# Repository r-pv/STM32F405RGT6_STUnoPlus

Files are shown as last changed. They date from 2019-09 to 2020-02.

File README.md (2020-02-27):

# STM32F405RGT6 STUno+

An ST development board based on the STM32F405RGT6/STM32F405RG (Clock: 168MHz, Flash: 1024Kb, Ram:194Kb) MCU (LQFP-64) compatible with STM32Duino (Arduino).

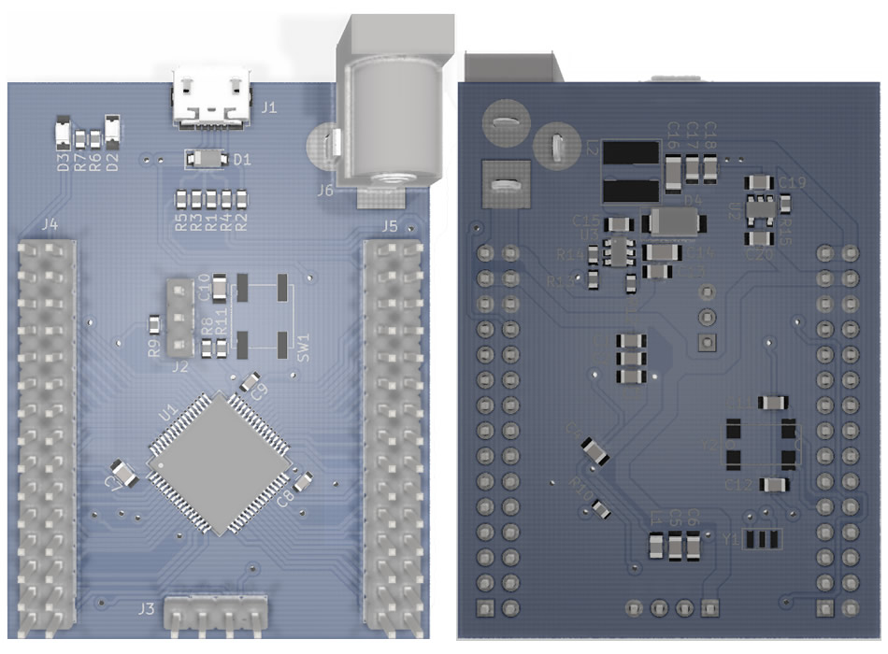
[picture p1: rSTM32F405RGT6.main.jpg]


## Pinout:

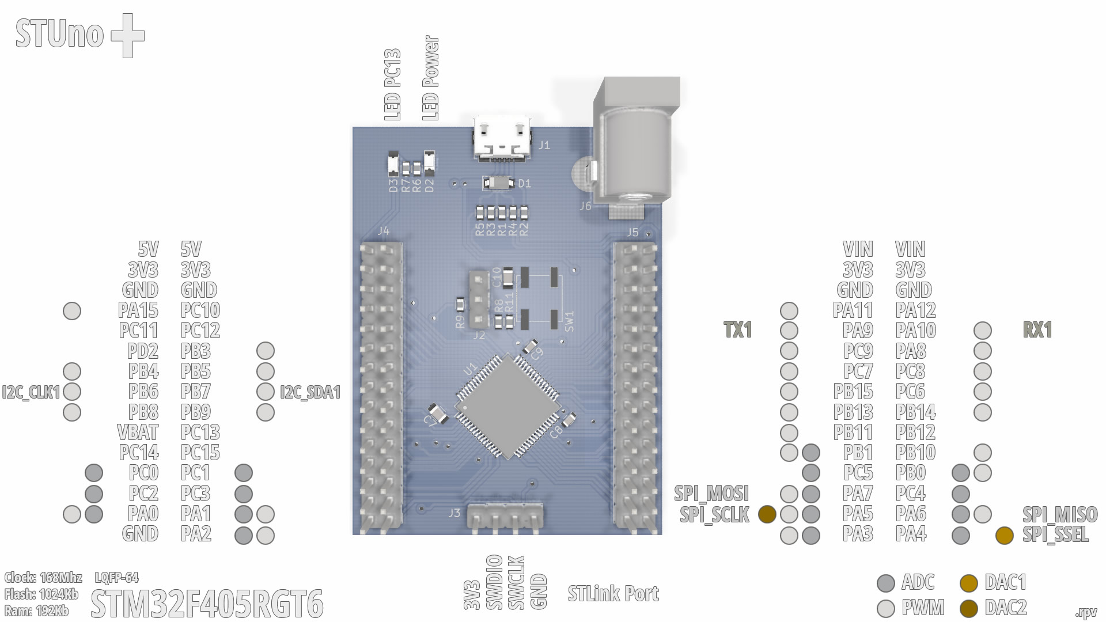
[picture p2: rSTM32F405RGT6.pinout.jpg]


## Files and Folders description

- **RBOARD_F405RGT6** it's the variant board for the STM32 Arduino Core.
- **rSTM32F405RGT6_B** it's the KiCAD 5.1.2 project.
- **rSTM32F405RGT6.schematic.pdf** the schematic.

## Install

- This requires the [STM32 core for arduino](https://github.com/stm32duino/Arduino_Core_STM32/), the ST original.
- I used this [guide to add the board](https://github.com/stm32duino/wiki/wiki/Add-a-new-variant-(board)), you can check it or continue with my suggestions to install the new board.
- Copy the **"RBOARD_F405RGT6"** folder to the Arduino **"variants"** folder, in win7 is located at: **c:\Users\\<USERNAME\>\AppData\Local\Arduino15\packages\STM32\hardware\stm32\1.8.0\variants**
- Edit the **"boards.txt"** file, in win7 is located at a lever up than the "variants" folder, search for the **Generic F4** board line and add the lines to leave it as I show you next:

```
# Adafruit Feather STM32F405 board
GenF4.menu.pnum.FEATHER_F405=Adafruit Feather STM32F405
GenF4.menu.pnum.FEATHER_F405.upload.maximum_size=1048576
GenF4.menu.pnum.FEATHER_F405.upload.maximum_data_size=131072
GenF4.menu.pnum.FEATHER_F405.build.board=FEATHER_F405
GenF4.menu.pnum.FEATHER_F405.build.product_line=STM32F405xx
GenF4.menu.pnum.FEATHER_F405.build.variant=FEATHER_F405

# STM32F405RGT6 STUnoPlus board
GenF4.menu.pnum.RBOARD_F405RGT6=STM32F405RGT6 STUnoPlus
GenF4.menu.pnum.RBOARD_F405RGT6.upload.maximum_size=1048576
GenF4.menu.pnum.RBOARD_F405RGT6.upload.maximum_data_size=131072
GenF4.menu.pnum.RBOARD_F405RGT6.build.board=RBOARD_F405RGT6
GenF4.menu.pnum.RBOARD_F405RGT6.build.product_line=STM32F405xx
GenF4.menu.pnum.RBOARD_F405RGT6.build.variant=RBOARD_F405RGT6
```
(add after the _"# Adafruit Feather STM32F405 board"_ section).

That's all.

So on the arduino IDE, on the **boards** menu pick the option _"Generic STM32F4 series"_ and the **board part number:** suboption pick the _"STM32F405RGT6 STUnoPlus"_ option.

**Note:** while adafruit board and mine use the same MCU there are not compatible variants: adafruit uses a 12mhz external crystal, mine uses an 8mhz.

## The real board

**Front**

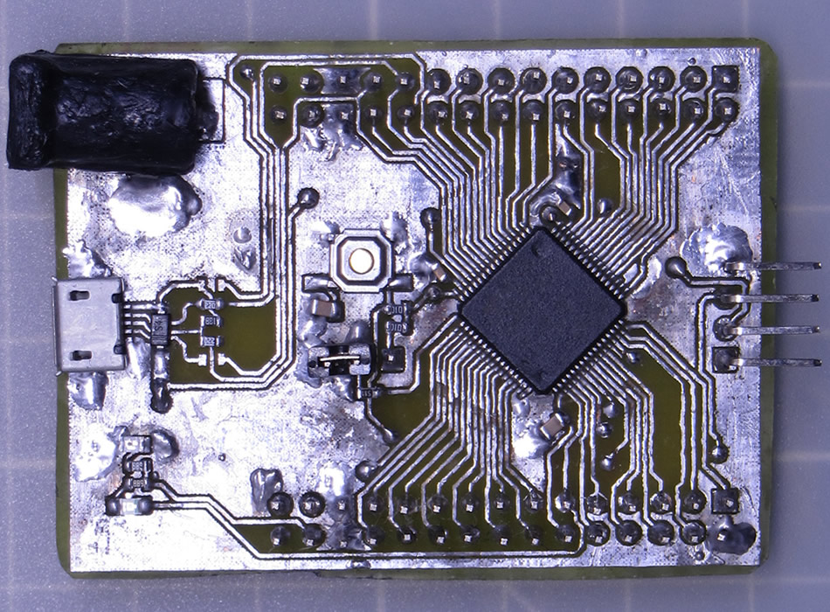
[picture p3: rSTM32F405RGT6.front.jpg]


_*I submerge the boards on a painters solvent bath to clean the flux residue which I haven't any problem until the DC jack came, as you see, didn't took the solvent bath kindly :P_

**Back**

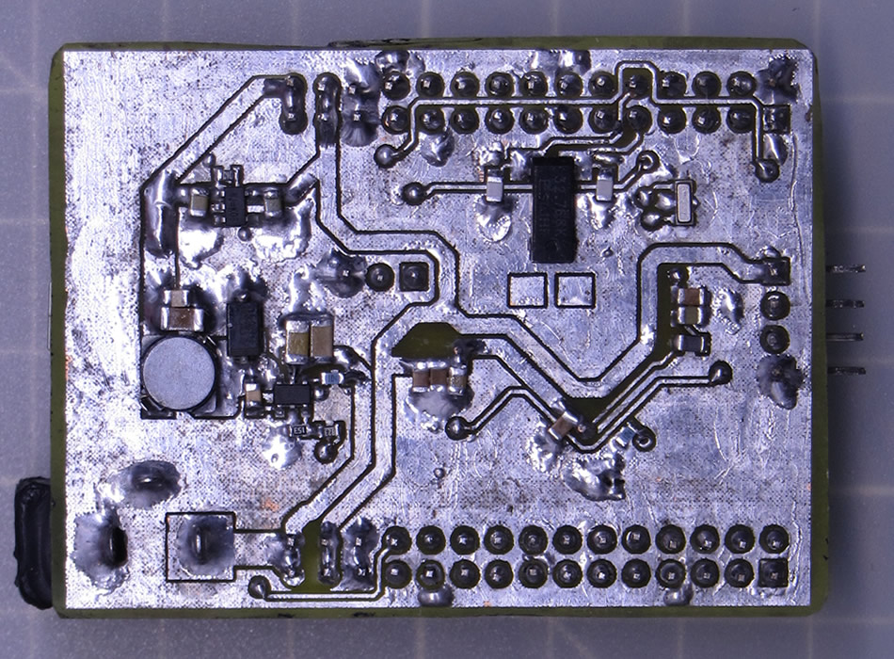
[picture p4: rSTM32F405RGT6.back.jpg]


_*The footprint for the second crystal (Y2) was wrong on this board but it's already corrected on the KiCAD files._

## Running some tests

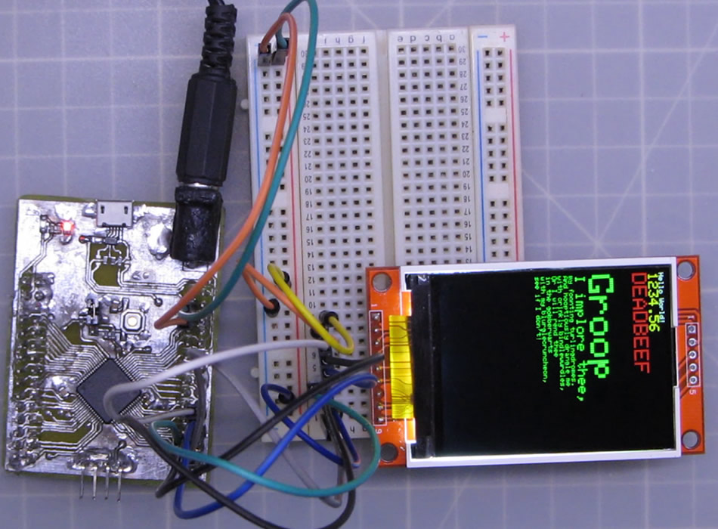
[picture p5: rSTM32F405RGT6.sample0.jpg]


The **STUno+** running the Adafruit ILI9341 library over hardware SPI.

_Video in progress..._

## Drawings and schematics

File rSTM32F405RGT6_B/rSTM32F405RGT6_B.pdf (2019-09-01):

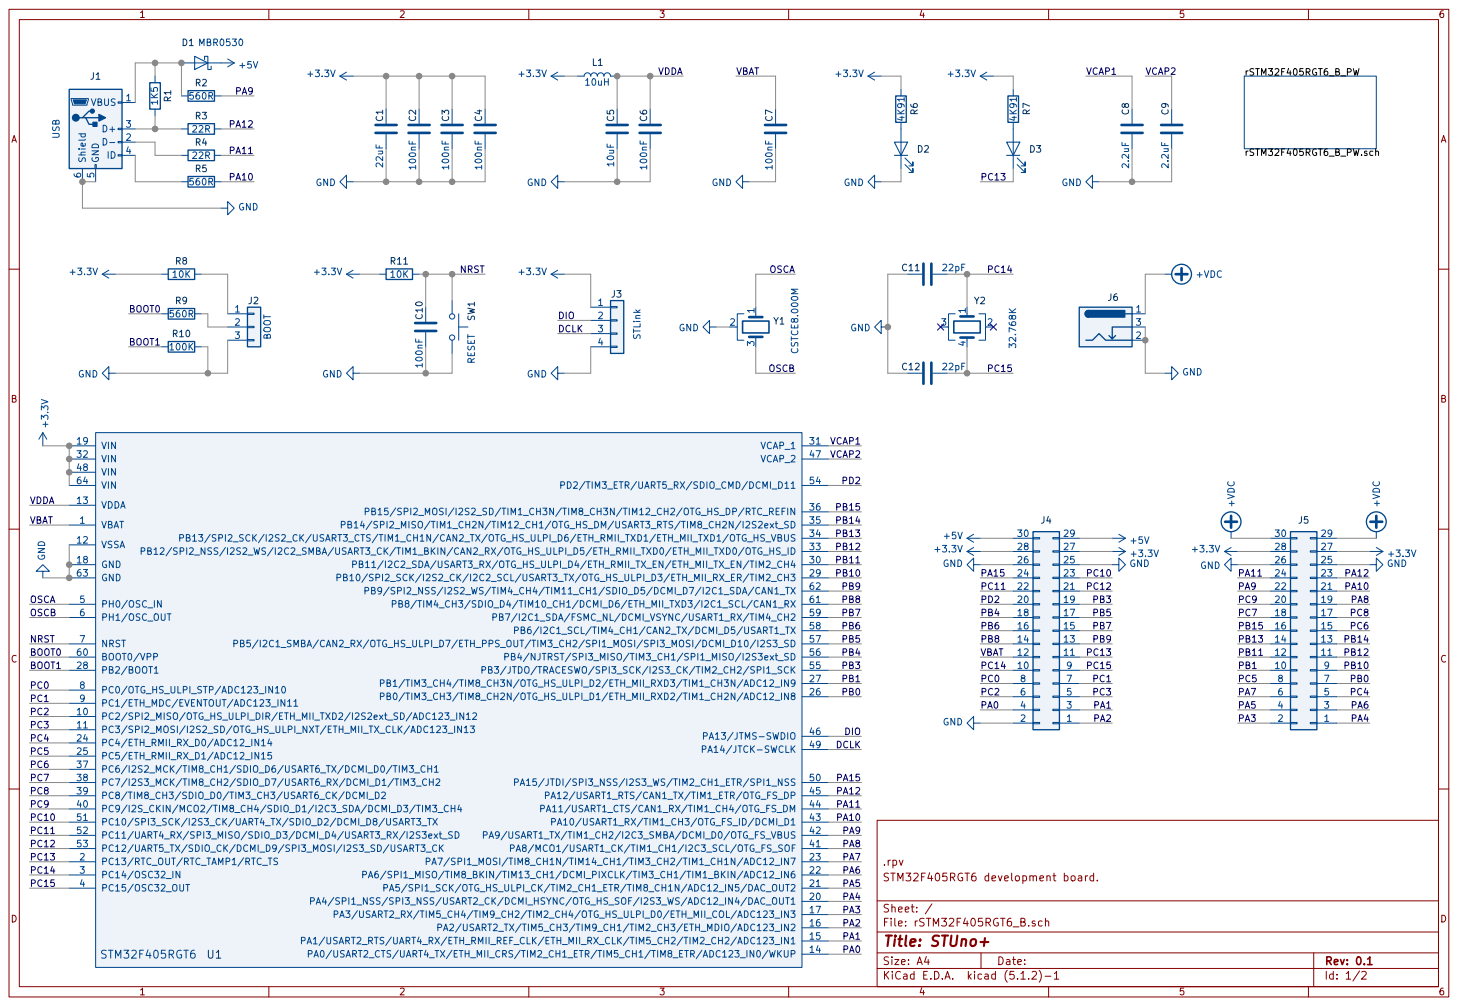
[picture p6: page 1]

File: rSTM32F405RGT6_B.sch Sheet: / STM32F405RGT6 development board.

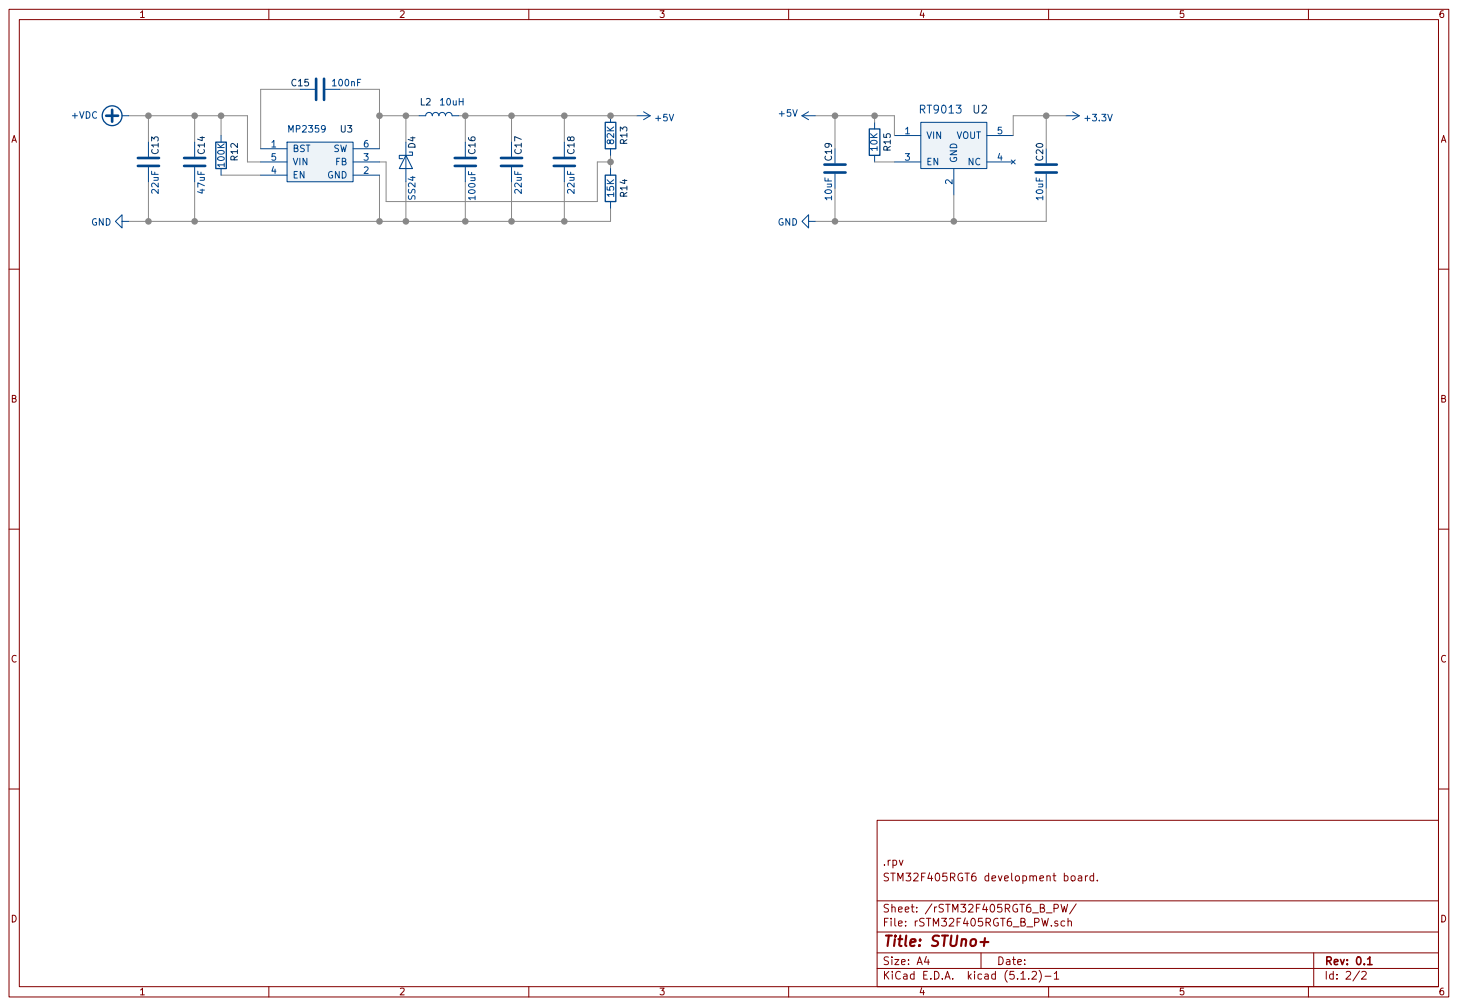
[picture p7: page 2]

2 EN 3 NC 4 VOUT 5 RT9013 U2 10K R15 +5V R12 100K GND

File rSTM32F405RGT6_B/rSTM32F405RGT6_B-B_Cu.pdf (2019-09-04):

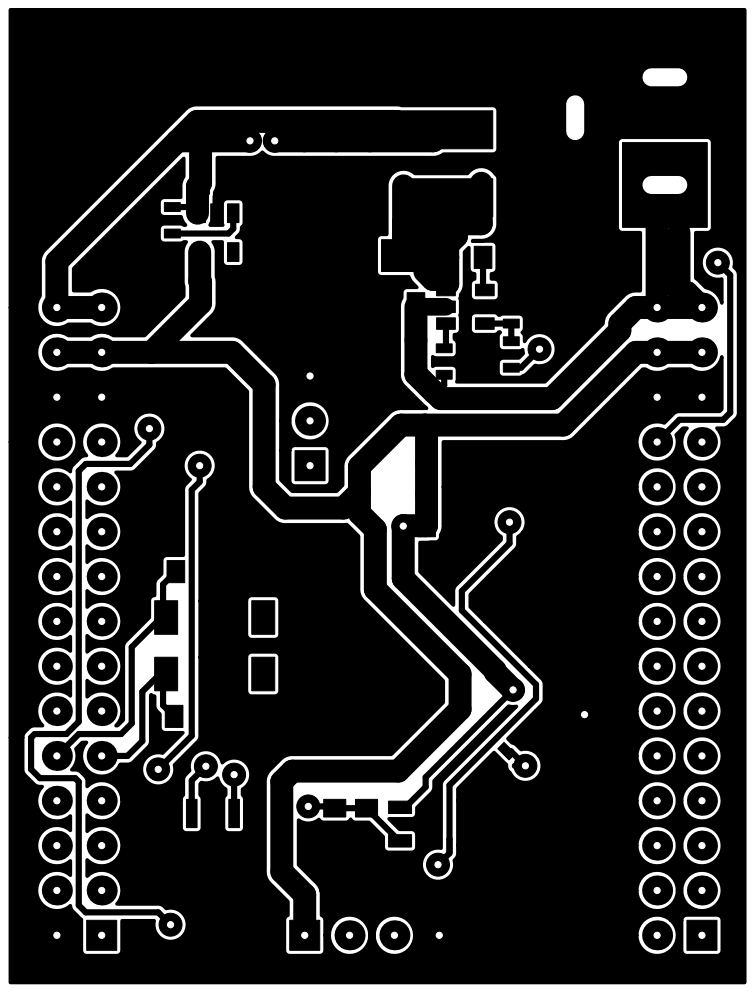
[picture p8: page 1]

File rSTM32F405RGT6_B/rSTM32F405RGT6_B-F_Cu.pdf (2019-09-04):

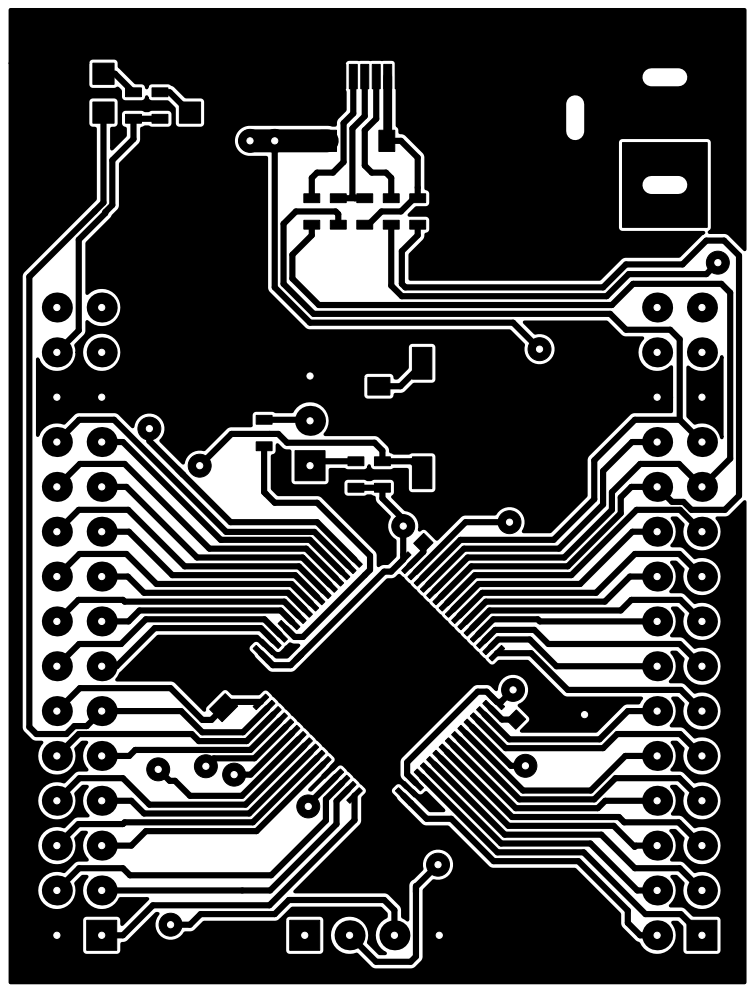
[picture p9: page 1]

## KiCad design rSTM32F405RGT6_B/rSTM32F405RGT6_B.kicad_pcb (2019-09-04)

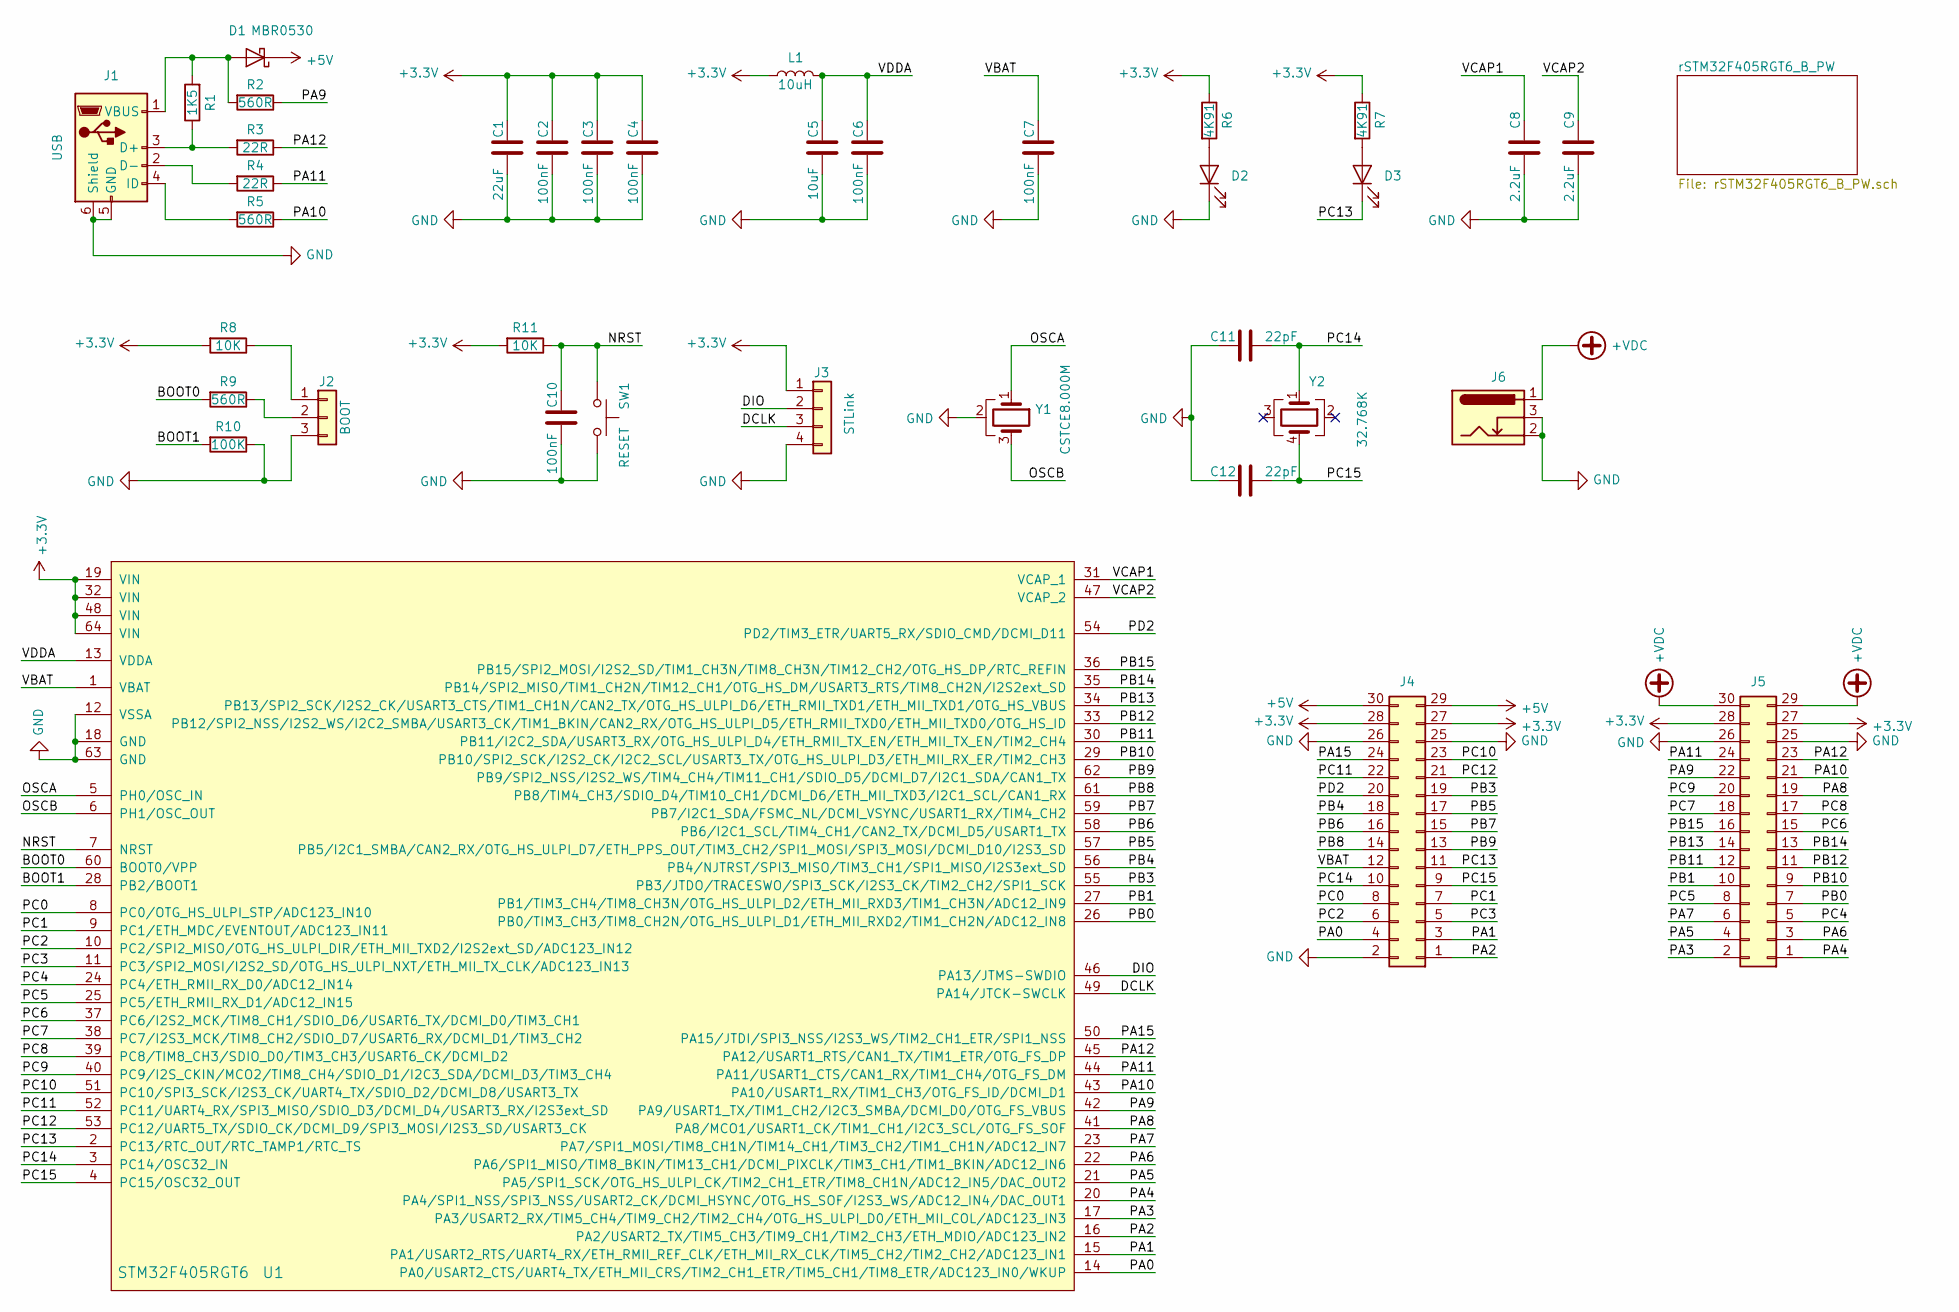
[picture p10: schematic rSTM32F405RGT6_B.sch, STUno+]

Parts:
C1: 22uF; C_0805
C2, C3, C4, C6, C7, C10: 100nF; C_0805
C5: 10uF; C_0805
C8, C9: 2.2uF; C_0603
C11, C12: 22pF; C_0805
D1: MBR0530; D_SOD-123
D2, D3: LED; LED_0805
J1: USB; USB_Micro-B_Molex_47346-0001
J2: BOOT; Pin_Header_Straight_1x03_Pitch2.54mm
J3: STLink; Pin_Header_Straight_1x04_Pitch2.54mm
J4, J5: Pin_Header_Straight_2x15_Pitch2.54mm
J6: JACK_ALIM
L1: 10uH; L_0805
R1: 1K5; R_0603
R2, R5, R9: 560R; R_0603
R3, R4: 22R; R_0603
R6, R7: 4K91; R_0603
R8, R11: 10K; R_0603
R10: 100K; R_0603
SW1: RESET; Switch_SMD_5.2x6.4_reset
U1: STM32F405RGT6; LQFP-64_10x10mm_Pitch0.5mm
Y1: CSTCE8.000M; Crystal_CSTCE_3pin_3.2x1.3
Y2: 32.768K; Crystal_4pin_SMD_2.5x4.6

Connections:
+3V3: C1.1, C2.1, C3.1, C4.1, J3.1, J4.27, J4.28, J5.27, J5.28, L1.1, R6.1, R7.1, R8.2, R11.2, U1.19 (VIN), U1.32 (VIN), U1.48 (VIN), U1.64 (VIN); also elsewhere on the board
+5V: D1.1 (K), J4.29, J4.30; also elsewhere on the board
+VDC: J5.29, J5.30, J6.1; also elsewhere on the board
/BOOT0: R9.2, U1.60 (BOOT0/VPP)
/BOOT1: R10.2, U1.28 (PB2/BOOT1)
/DCLK: J3.3, U1.49 (PA14/JTCK-SWCLK)
/DIO: J3.2, U1.46 (PA13/JTMS-SWDIO)
/NRST: C10.1, R11.1, SW1.1, U1.7 (NRST)
/OSCA: U1.5 (PH0/OSC_IN), Y1.1
/OSCB: U1.6 (PH1/OSC_OUT), Y1.3
/PA0: J4.4, U1.14 (PA0/USART2_CTS/UART4_TX/ETH_MII_CRS/TIM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)
/PA1: J4.3, U1.15 (PA1/USART2_RTS/UART4_RX/ETH_RMII_REF_CL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)
/PA2: J4.1, U1.16 (PA2/USART2_TX/TIM5_CH3/TIM9_CH1/TIM2_CH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)
/PA3: J5.2, U1.17 (PA3/USART2_RX/TIM5_CH4/TIM9_CH2/TIM2_CH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)
/PA4: J5.1, U1.20 (PA4/SPI1_NSS/SPI3_NSS/USART2_CK/DCMI_HS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)
/PA5: J5.4, U1.21 (PA5/SPI1_SCK/OTG_HS_ULPI_CK/TIM2_CH1_ET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)
/PA6: J5.3, U1.22 (PA6/SPI1_MISO/TIM8_BKIN/TIM13_CH1/DCMI_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)
/PA7: J5.6, U1.23 (PA7/SPI1_MOSI/TIM8_CH1N/TIM14_CH1/TIM3_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)
/PA8: J5.19, U1.41 (PA8/MCO1/USART1_CK/TIM1_CH1/I2C3_SCL/OT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)
/PA9: J5.22, R2.1, U1.42 (PA9/USART1_TX/TIM1_CH2/I2C3_SMBA/DCMI_D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)
/PA10: J5.21, R5.1, U1.43 (PA10/USART1_RX/TIM1_CH3/OTG_FS_ID/DCMI_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)
/PA11: J5.24, R4.1, U1.44 (PA11/USART1_CTS/CAN1_RX/TIM1_CH4/OTG_FS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)
/PA12: J5.23, R3.1, U1.45 (PA12/USART1_RTS/CAN1_TX/TIM1_ETR/OTG_FS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)
/PA15: J4.24, U1.50 (PA15/JTDI/SPI3_NSS/I2S3_WS/TIM2_CH1_ETR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)
/PB0: J5.7, U1.26 (PB0/TIM3_CH3/TIM8_CH2N/OTG_HS_ULPI_D1/E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)
/PB1: J5.10, U1.27 (PB1/TIM3_CH4/TIM8_CH3N/OTG_HS_ULPI_D2/E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)
/PB3: J4.19, U1.55 (PB3/JTDO/TRACESWO/SPI3_SCK/I2S3_CK/TIM2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)
/PB4: J4.18, U1.56 (PB4/NJTRST/SPI3_MISO/TIM3_CH1/SPI1_MISO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)
/PB5: J4.17, U1.57 (PB5/I2C1_SMBA/CAN2_RX/OTG_HS_ULPI_D7/ET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)
/PB6: J4.16, U1.58 (PB6/I2C1_SCL/TIM4_CH1/CAN2_TX/DCMI_D5/U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)
/PB7: J4.15, U1.59 (PB7/I2C1_SDA/FSMC_NL/DCMI_VSYNC/USART1_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)
/PB8: J4.14, U1.61 (PB8/TIM4_CH3/SDIO_D4/TIM10_CH1/DCMI_D6/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)
/PB9: J4.13, U1.62 (PB9/SPI2_NSS/I2S2_WS/TIM4_CH4/TIM11_CH1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)
/PB10: J5.9, U1.29 (PB10/SPI2_SCK/I2S2_CK/I2C2_SCL/USART3_T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)
/PB11: J5.12, U1.30 (PB11/I2C2_SDA/USART3_RX/OTG_HS_ULPI_D4/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)
/PB12: J5.11, U1.33 (PB12/SPI2_NSS/I2S2_WS/I2C2_SMBA/USART3_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)
/PB13: J5.14, U1.34 (PB13/SPI2_SCK/I2S2_CK/USART3_CTS/TIM1_C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)
/PB14: J5.13, U1.35 (PB14/SPI2_MISO/TIM1_CH2N/TIM12_CH1/OTG_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)
/PB15: J5.16, U1.36 (PB15/SPI2_MOSI/I2S2_SD/TIM1_CH3N/TIM8_C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)
/PC0: J4.8, U1.8 (PC0/OTG_HS_ULPI_STP/ADC123_IN10)
/PC1: J4.7, U1.9 (PC1/ETH_MDC/EVENTOUT/ADC123_IN11)
/PC2: J4.6, U1.10 (PC2/SPI2_MISO/OTG_HS_ULPI_DIR/ETH_MII_T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)
/PC3: J4.5, U1.11 (PC3/SPI2_MOSI/I2S2_SD/OTG_HS_ULPI_NXT/E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)
/PC4: J5.5, U1.24 (PC4/ETH_RMII_RX_D0/ADC12_IN14)
/PC5: J5.8, U1.25 (PC5/ETH_RMII_RX_D1/ADC12_IN15)
/PC6: J5.15, U1.37 (PC6/I2S2_MCK/TIM8_CH1/SDIO_D6/USART6_TX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)
/PC7: J5.18, U1.38 (PC7/I2S3_MCK/TIM8_CH2/SDIO_D7/USART6_RX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)
/PC8: J5.17, U1.39 (PC8/TIM8_CH3/SDIO_D0/TIM3_CH3/USART6_CK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)
/PC9: J5.20, U1.40 (PC9/I2S_CKIN/MCO2/TIM8_CH4/SDIO_D1/I2C3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)
/PC10: J4.23, U1.51 (PC10/SPI3_SCK/I2S3_CK/UART4_TX/SDIO_D2/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)
/PC11: J4.22, U1.52 (PC11/UART4_RX/SPI3_MISO/SDIO_D3/DCMI_D4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)
/PC12: J4.21, U1.53 (PC12/UART5_TX/SDIO_CK/DCMI_D9/SPI3_MOSI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)
/PC13: D3.1 (K), J4.11, U1.2 (PC13/RTC_OUT/RTC_TAMP1/RTC_TS)
/PC14: C11.1, J4.10, U1.3 (PC14/OSC32_IN), Y2.1
/PC15: C12.1, J4.9, U1.4 (PC15/OSC32_OUT), Y2.4
/PD2: J4.20, U1.54 (PD2/TIM3_ETR/UART5_RX/SDIO_CMD/DCMI_D11)
/VBAT: C7.1, J4.12, U1.1 (VBAT)
/VCAP1: C8.1, U1.31 (VCAP_1)
/VCAP2: C9.1, U1.47 (VCAP_2)
/VDDA: C5.1, C6.1, L1.2, U1.13 (VDDA)
GND: C1.2, C2.2, C3.2, C4.2, C5.2, C6.2, C7.2, C8.2, C9.2, C10.2, C11.2, C12.2, D2.1 (K), J1.5 (GND), J1.6 (Shield), J2.3, J3.4, J4.2, J4.25, J4.26, J5.25, J5.26, J6.2, J6.3, R10.1, SW1.2, U1.12 (VSSA), U1.18 (GND), U1.63 (GND), Y1.2; also elsewhere on the board
unnamed: D1.2 (A), J1.1 (VBUS), R1.2, R2.2
unnamed: D2.2 (A), R6.2
unnamed: D3.2 (A), R7.2
unnamed: J1.2 (D-), R4.2
unnamed: J1.3 (D+), R1.1, R3.2
unnamed: J1.4 (ID), R5.2
unnamed: J2.1, R8.1
unnamed: J2.2, R9.1

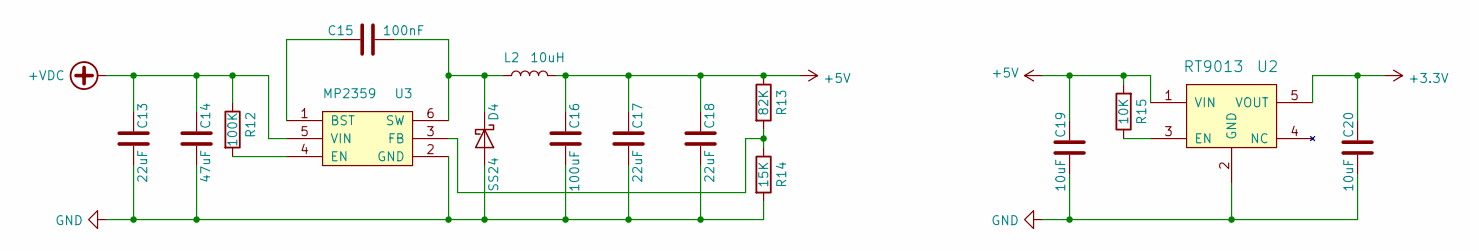
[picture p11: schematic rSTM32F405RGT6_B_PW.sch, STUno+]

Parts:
C13, C17, C18: 22uF; C_0805
C14: 47uF; C_1206
C15: 100nF; C_0805
C16: 100uF; C_1206
C19, C20: 10uF; C_0805
D4: SS24; D_SMA
L2: 10uH; Inductor-CD54
R12: 100K; R_0603
R13: 82K; R_0603
R14: 15K; R_0603
R15: 10K; R_0603
U2: RT9013; SOT-23-5
U3: MP2359; SOT-23-6

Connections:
+3V3: C20.1, U2.5 (VOUT); also elsewhere on the board
+5V: C16.1, C17.1, C18.1, C19.1, L2.2, R13.1, R15.2, U2.1 (VIN); also elsewhere on the board
+VDC: C13.1, C14.1, R12.1, U3.5 (VIN); also elsewhere on the board
GND: C13.2, C14.2, C16.2, C17.2, C18.2, C19.2, C20.2, D4.2 (A), R14.2, U2.2 (GND), U3.2 (GND); also elsewhere on the board
unnamed: C15.1, D4.1 (K), L2.1, U3.6 (SW)
unnamed: C15.2, U3.1 (BST)
unnamed: R12.2, U3.4 (EN)
unnamed: R13.2, R14.1, U3.3 (FB)
unnamed: R15.1, U2.3 (EN)

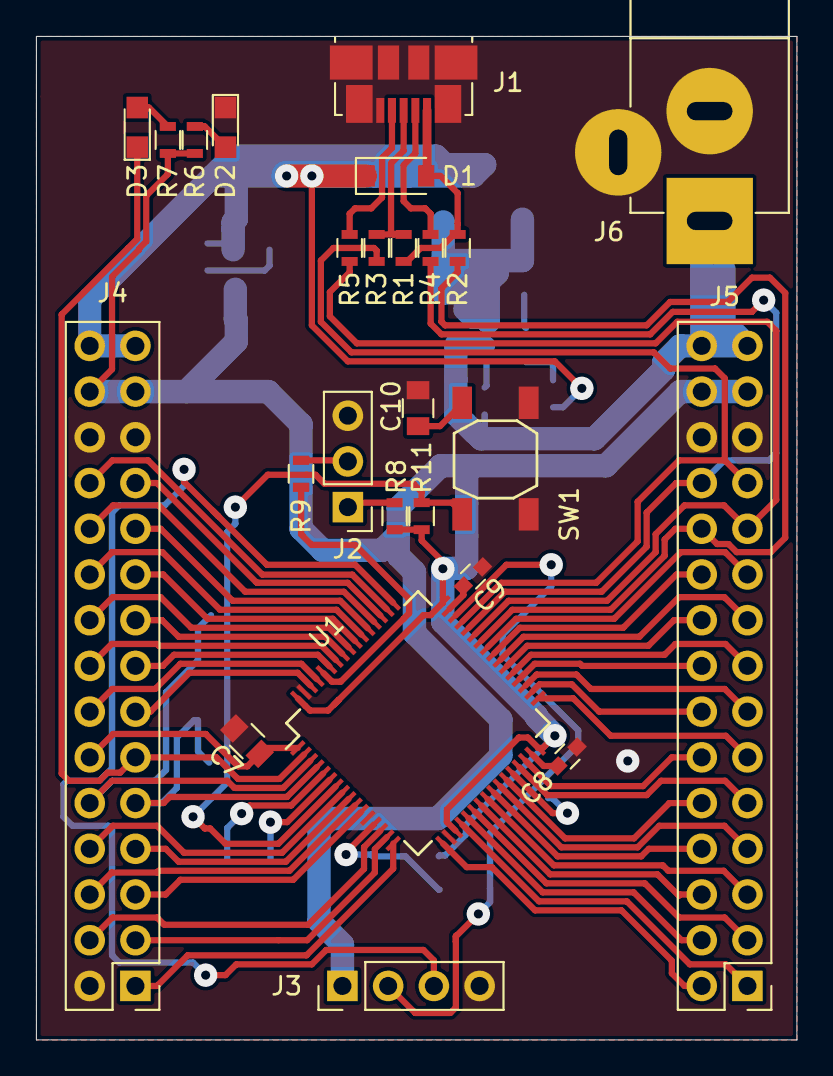
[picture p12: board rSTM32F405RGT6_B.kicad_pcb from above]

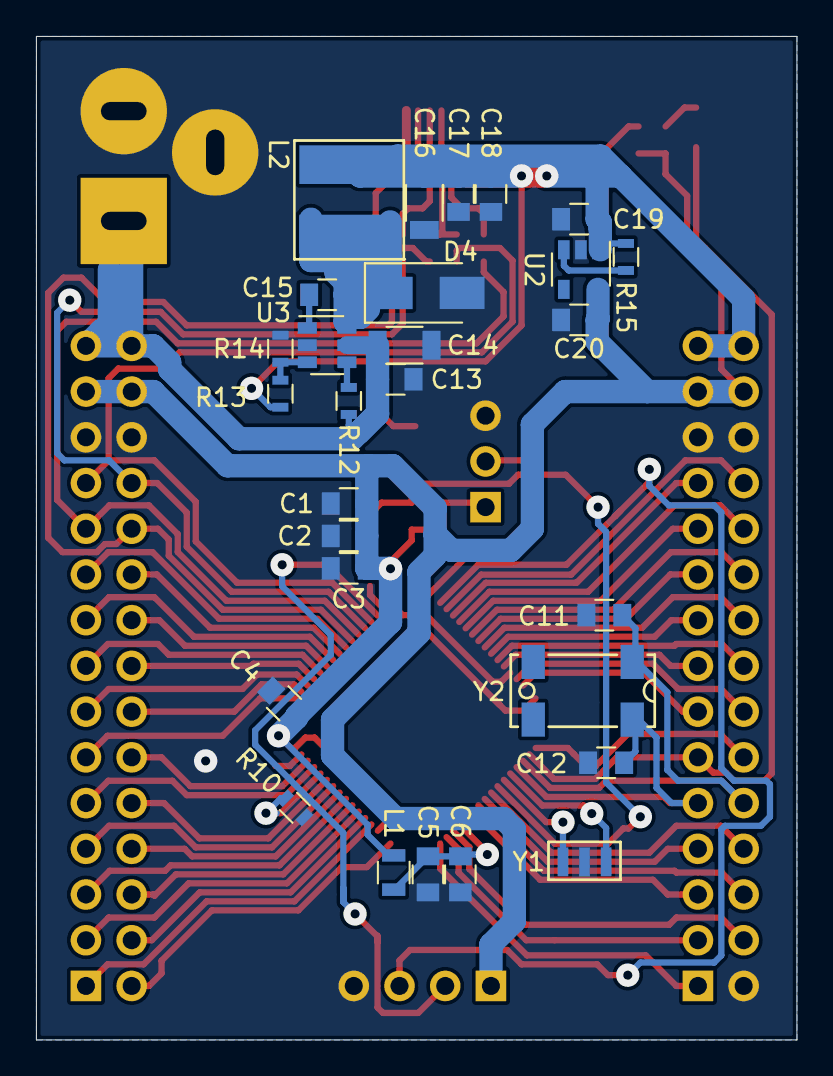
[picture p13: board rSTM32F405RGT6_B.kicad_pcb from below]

Board: 2 copper layers, 42.2 x 55.8 mm, 53 parts (28 on the bottom side), 74 nets.

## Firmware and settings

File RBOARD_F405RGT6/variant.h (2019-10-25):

/*
 *******************************************************************************
 * Copyright (c) 2017, STMicroelectronics
 * All rights reserved.
 *
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
 * THIS SOFTWARE IS PROVIDED BY THE COPYRIGHT HOLDERS AND CONTRIBUTORS "AS IS"
 * AND ANY EXPRESS OR IMPLIED WARRANTIES, INCLUDING, BUT NOT LIMITED TO, THE
 * IMPLIED WARRANTIES OF MERCHANTABILITY AND FITNESS FOR A PARTICULAR PURPOSE ARE
 * DISCLAIMED. IN NO EVENT SHALL THE COPYRIGHT HOLDER OR CONTRIBUTORS BE LIABLE
 * FOR ANY DIRECT, INDIRECT, INCIDENTAL, SPECIAL, EXEMPLARY, OR CONSEQUENTIAL
 * DAMAGES (INCLUDING, BUT NOT LIMITED TO, PROCUREMENT OF SUBSTITUTE GOODS OR
 * SERVICES; LOSS OF USE, DATA, OR PROFITS; OR BUSINESS INTERRUPTION) HOWEVER
 * CAUSED AND ON ANY THEORY OF LIABILITY, WHETHER IN CONTRACT, STRICT LIABILITY,
 * OR TORT (INCLUDING NEGLIGENCE OR OTHERWISE) ARISING IN ANY WAY OUT OF THE USE
 * OF THIS SOFTWARE, EVEN IF ADVISED OF THE POSSIBILITY OF SUCH DAMAGE.
 *******************************************************************************
 */
#ifndef _VARIANT_ARDUINO_STM32_
#define _VARIANT_ARDUINO_STM32_

/*----------------------------------------------------------------------------
 *        Headers
 *----------------------------------------------------------------------------*/
#ifdef __cplusplus
extern "C"{
#endif // __cplusplus

/*----------------------------------------------------------------------------
 *        Pins
 *----------------------------------------------------------------------------*/
//.with.the.USB.on.top.and.bottom-to-left-to-right.naming;
//.this.weird.naming.due.to.comply.with.the.analog.pin.number.being>=NUM_ANALOG_INPUTS.in.this.case:16
// Bottom.side
#define PA13   0
#define PA14   1
// Left.Side
#define PA15   2
#define PC10   3
#define PC11   4
#define PC12   5
#define PD2    6
#define PB3    7
#define PB4    8
#define PB5    9
#define PB6    10
#define PB7    11
#define PB8    12
#define PB9    13
//VBAT
#define PC13   14
#define PC14   15
#define PC15   16
#define PC0    17
#define PC1    18
#define PC2    19
#define PC3    20
#define PA0    21
#define PA1    22
//GND
#define PA2    23
// Right.side
#define PA3    24
#define PA4    25
#define PA5    26
#define PA6    27
#define PA7    28
#define PC4    29
#define PC5    30
#define PB0    31
#define PB1    32
#define PB10   33
#define PB11   34
#define PB12   35
#define PB13   36
#define PB14   37
#define PB15   38
#define PC6    39
#define PC7    40
#define PC8    41
#define PC9    42
#define PA8    43
#define PA9    44
#define PA10   45
#define PA11   46
#define PA12   47

// Define pin names to match digital pin number --> Dx
// It could be used with preprocessor tests (e.g. #if PXn == 3)
// so an enum will not work.
// !!!
// !!! Copy the digitalPin[] array from the variant.cpp
// !!! and remove all '_': PX_n --> PXn
// !!! For NC, comment the line to warn x pin number is NC
// !!! // x is NC
// !!! For duplicated pin name, comment the line to warn x pin number
// !!! is PXn which is already defined with y pin number
// !!! // x is PXn (y)
// !!! Ex:
// !!! ...
// !!! #define PA4  20 // A14
// !!! #define PB4  21
// !!! #define PB5  22
// !!! #define PB3  23
// !!! // 24 is PA4 (20)
// !!! // 25 is PB4 (21)
// !!! #define PA2  26 // A15
// !!! ...
//#define PXn x

// This must be a literal
// It is used with preprocessor tests (e.g. #if NUM_DIGITAL_PINS > 3)
// so an enum will not work.
#define NUM_DIGITAL_PINS        57

// Allow to define Arduino style alias for analog input pin number --> Ax
// All pins are digital, analog inputs are a subset of digital pins
// and must be contiguous to be able to loop on each value
// This must be a literal with a value less than or equal to MAX_ANALOG_INPUTS
// defined in pin_arduino.h
// It is used with preprocessor tests (e.g. #if NUM_ANALOG_INPUTS > 3)
// so an enum will not work.
// !!!
// !!! It must be aligned with the number of analog PinName
// !!! defined in digitalPin[] array in variant.cpp
// !!!
#define NUM_ANALOG_INPUTS       16
// Define digital pin number of the first analog input  (i.e. which digital pin is A0)
// First analog pin value (A0) must be greater than or equal to NUM_ANALOG_INPUTS
#define NUM_ANALOG_FIRST        17

// Below ADC, DAC and PWM definitions already done in the core
// Could be redefined here if needed
// ADC resolution is 12bits
//#define ADC_RESOLUTION          12
//#define DACC_RESOLUTION         12

// PWM resolution
//#define PWM_RESOLUTION          8
//#define PWM_FREQUENCY           1000
//#define PWM_MAX_DUTY_CYCLE      255

// On-board LED pin number
#define LED_BUILTIN             PC13
#define LED_GREEN               LED_BUILTIN

// On-board user button
#define USER_BTN                x

// Below SPI and I2C definitions already done in the core
// Could be redefined here if differs from the default one
// SPI Definitions
// SPI Definitions
#define PIN_SPI_SS              PA4
#define PIN_SPI_MOSI            PA7
#define PIN_SPI_MISO            PA6
#define PIN_SPI_SCK             PA5

// I2C Definitions
#define PIN_WIRE_SDA            PB7  // Default for Arduino connector compatibility
#define PIN_WIRE_SCL            PB6  // Default for Arduino connector compatibility

// Timer Definitions
// Do not use timer used by PWM pins when possible. See PinMap_PWM.
#define TIMER_TONE              TIM3

// Do not use basic timer: OC is required
#define TIMER_SERVO             TIM2  //TODO: advanced-control timers don't work

// UART Definitions
#define SERIAL_UART_INSTANCE    1
// Default pin used for 'Serial' instance
// Mandatory for Firmata
#define PIN_SERIAL_RX           PA10
#define PIN_SERIAL_TX           PA9

// UART Definitions
// Define here Serial instance number to map on Serial generic name
//#define SERIAL_UART_INSTANCE    x //ex: 2 for Serial2 (USART2)
// DEBUG_UART could be redefined to print on another instance than 'Serial'
//#define DEBUG_UART              ((USART_TypeDef *) U(S)ARTX) // ex: USART3
// DEBUG_UART baudrate, default: 9600 if not defined
//#define DEBUG_UART_BAUDRATE     x
// DEBUG_UART Tx pin name, default: the first one found in PinMap_UART_TX for DEBUG_UART
//#define DEBUG_PINNAME_TX        PX_n // PinName used for TX


// Optional PIN_SERIALn_RX and PIN_SERIALn_TX where 'n' is the U(S)ART number
// Used when user instanciate a hardware Serial using its peripheral name.
// Example: HardwareSerial mySerial(USART3);
// will use PIN_SERIAL3_RX and PIN_SERIAL3_TX if defined.
//#define PIN_SERIALn_RX          x // For U(S)ARTn RX
//#define PIN_SERIALn_TX          x // For U(S)ARTn TX
//#define PIN_SERIALLP1_RX        x // For LPUART1 RX
//#define PIN_SERIALLP1_TX        x // For LPUART1 TX

// SD card slot Definitions
// SD detect signal can be defined if required
//#define SD_DETECT_PIN           x
// SD Read/Write timeout, default value defined in STM32SD library
//#define SD_DATATIMEOUT          x
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

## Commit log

2019-09-01 KiCAD project.
    [rSTM32F405RGT6_B.kicad_pcb, rSTM32F405RGT6_B.sch, rSTM32F405RGT6_B_PW.sch]
2019-09-04 KiCAD Project
    Fixing some footprints.
    [rSTM32F405RGT6_B.kicad_pcb, rSTM32F405RGT6_B.sch]
2019-10-24 Pinout updated: added ADC and PWM pins.
2019-10-25 Fixed a bug with the analogs.
    Fixed a mistake I made.
    [variant.cpp, variant.h]
